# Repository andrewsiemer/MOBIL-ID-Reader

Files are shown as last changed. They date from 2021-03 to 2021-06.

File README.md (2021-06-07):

# MOBIL-ID Reader



## What is MOBIL-ID?
#### A Python web service & embedded reader for Apple PassKit

The MOBIL-ID project is an engineering systems capstone project for Oklahoma Christian University. The team’s mission statement is to create a mobile platform front-end to Oklahoma Christian University’s user management system. Students and Faculty will use their mobile ID to gain chapel attendance, enter the university cafeteria, and pay using Eagle Bucks.

### MOBIL-ID Reader
The MOBIL-ID Reader is a slave device responsible for scanning MOBIL-ID passes. It captures the QR data from a scanned pass and sends it in a GET request to the MOBIL-ID Server. The MOBIL-ID Server returns the associated user ID number. The MOBIL-ID Reader then hands the ID number to the transactional system via the USB connection. Below is a guide to creating a fully functional MOBIL-ID Reader.

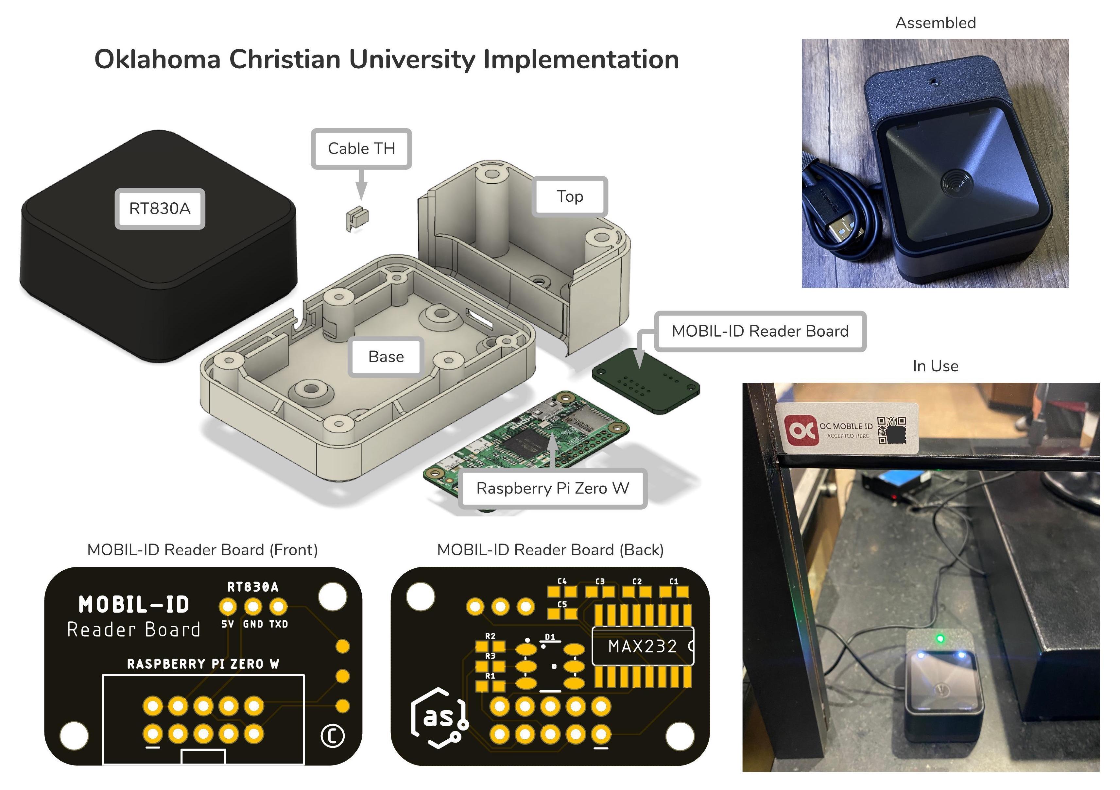
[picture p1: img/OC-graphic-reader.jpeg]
OC-graphic


### MOBIL-ID Server
The MOBIL-ID Server is a Python web service responsible for creating, deploying, and updating passes using Apple PassKit & Google Pay API. It tracks the pass’s complete lifecycle. When a user requests a pass, the server gets the user's data from OC’s database, creates a new pass, and signs it before delivering it to the user. It keeps a log of every pass it creates. When a user adds the pass to Apple Wallet, the pass will send a registration request to our server. The server will log the device id and pass relationship. When users data is changed, the MOBIL-ID server then knows what device to send the update push notification to. If a user deletes a pass of their device, the server will receive a request to delete the pass and it will be deleted from the server’s database and no longer receive updates. The user will also recieve real-time push notifications when pass data has change. [View MOBIL-ID Server](https://github.com/andrewsiemer/MOBIL-ID-Server)

### The MOBIL-ID Team
* Andrew Siemer - Electrical/Software Engineer - Team Lead
* Jacob Button - Electrical/Software Engineer
* Kyla Tarpey - Electrical Engineer
* Zach Jones - Computer/Software Engineer

### Acknowledgments
- Steve Maher - Mentor
- Luke Hartman - Customer
- Peyton Chenault - System Integrator

This work is licensed under a
[Creative Commons Attribution-NonCommercial-ShareAlike 4.0 International License](http://creativecommons.org/licenses/by-nc-sa/4.0/).

---

## Hardware Setup
The Hardware Setup Guide is a long but detailed document that steps through the entire process of creating a MOBIL-ID Reader. The document can be viewed or downloaded from the link below.

### [View Hardware Setup Guide](https://docs.google.com/document/d/1EBEo_Zr7OZ9AODJT-2cf_hYnRvtXFjDW9OjWyJNuSes)

## Software Setup
### Prerequisites
* [Install Raspberry Pi OS LITE using Raspberry Pi Imager](https://www.raspberrypi.org/software/)
* [Headless Raspberry Pi Setup](https://pimylifeup.com/headless-raspberry-pi-setup/)

### Raspberry Pi First Boot
Before we start, check that you have:

* A clean installation of Raspberry Pi OS LITE on a microSD card
* Added the `ssh` file to the `/boot` directory
* Added the `wpa_supplicant.conf` file to the `/boot` directory

**You will not be able to continue without completing these steps. Use the links above to properly allow headless setup.**

If you are confident you have completed the steps above, put the microSD card into the Raspberry Pi and plug the USB power cable in.
You should hear a startup beep and the LED on the MOBIL-ID Reader Board should be magenta. If one of theses did not happen, you will need to troubleshoot your hardware setup.

### Login to Raspberry Pi Remotely
In macOS/Linux, open Terminal and enter:
```sh
ssh pi@raspberrypi.local
```
The default password is `raspberry`.

### Run the MOBIL-ID Reader Installer
Once you are logged into as user `pi` run:
``` sh
curl https://raw.githubusercontent.com/andrewsiemer/MOBIL-ID-Reader/main/install.sh > install.sh && sudo bash install.sh
```
This script installs software for the MOBIL-ID Reader on the Raspberry Pi.

This includes:

* Creating a new hostname & password
* Updating the package index files (apt-get update)
* Installing prerequisite software
* Installing MOBIL-ID software and examples
* Configuring boot options

**Run time ~20 minutes. Reboot recommended after install. EXISTING INSTALLATION, IF ANY, WILL BE OVERWRITTEN.**

> The MOBIL-ID Reader will not work correctly until the system has been rebooted.

---

## MOBIL-ID Reader Status Codes
Once the MOBIL-ID Reader software is installed correctly and has been rebooted, the unit will use the LED on the MOBIL-ID Reader Board to show its status.

| LED Color | Description |
| --- | --- |
| Magenta | reader powered, starting program (~1 min) |
| Turquoise | connecting to network/updating software (<30 secs) |
| Yellow | waiting to connect to server |
| Green | connected, ready to scan |
| Red | processing scan |

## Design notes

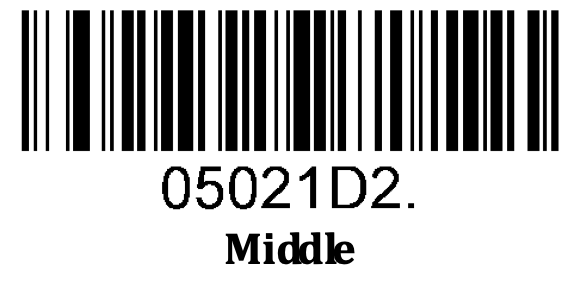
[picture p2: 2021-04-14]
img/beep-medium.png

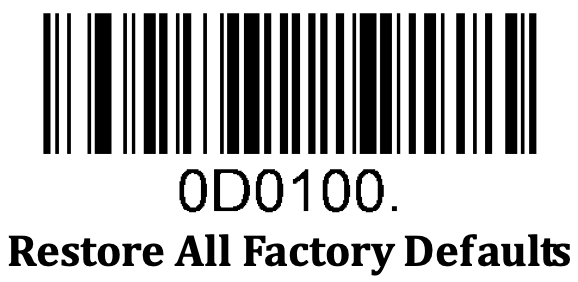
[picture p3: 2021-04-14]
img/restore-defaults.png

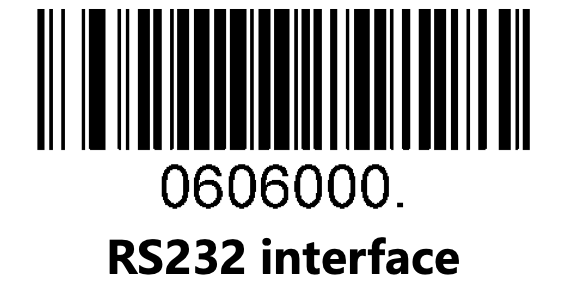
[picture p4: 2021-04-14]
img/RS232.png

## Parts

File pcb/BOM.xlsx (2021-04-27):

Comment | Designator | Footprint | LCSC Part #
330 | R1 | 603 | C23138
330 | R2 | 603 | C23138
330 | R3 | 603 | C23138
1u | C1 | 603 | C15849
1u | C2 | 603 | C15849
1u | C3 | 603 | C15849
1u | C4 | 603 | C15849
1u | C5 | 603 | C15849
5050 RGB | D1 | 5050 | C193878 | C784540
Maxim MAX232 | MAX232 | MAX232ECWES | C26860

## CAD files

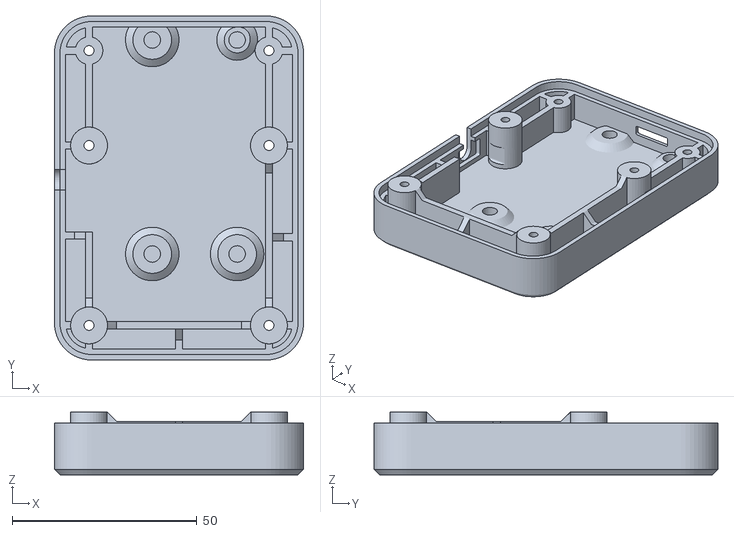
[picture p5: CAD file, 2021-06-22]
stl/Base.stl
67.5 x 93.2 x 17.0

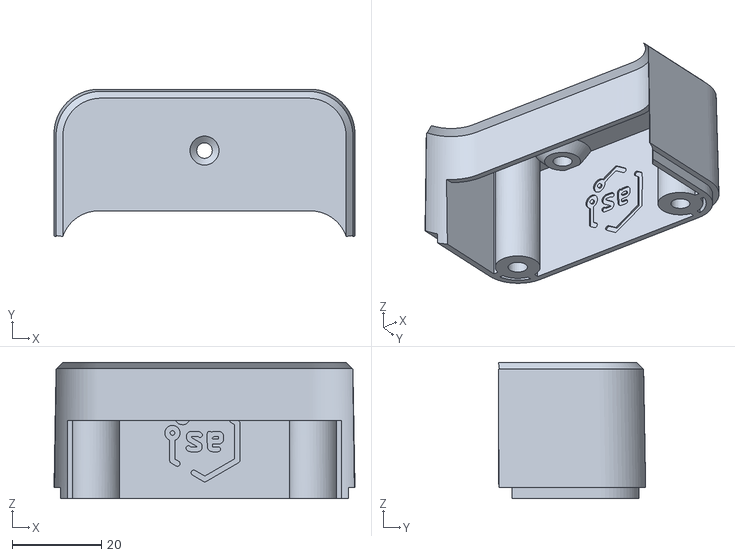
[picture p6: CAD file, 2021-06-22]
stl/Top.stl
67.5 x 33.1 x 30.5

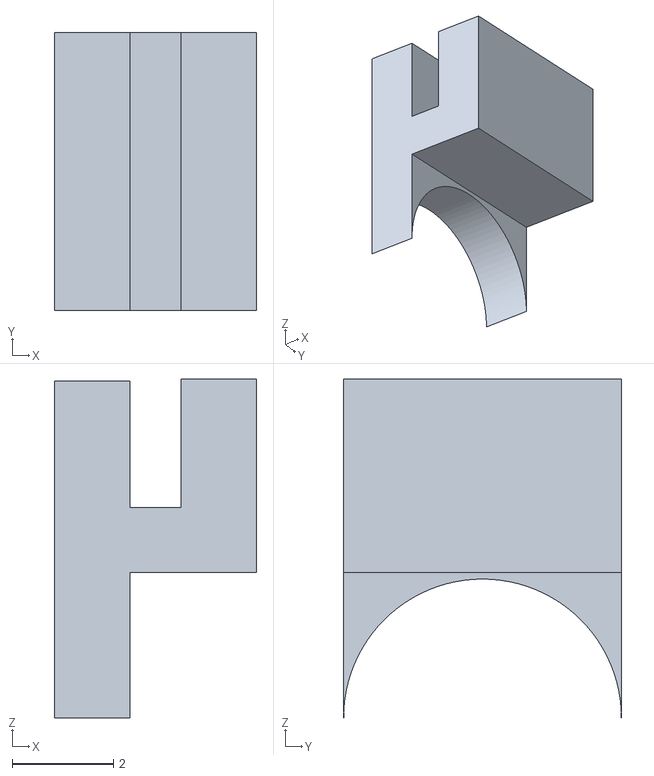
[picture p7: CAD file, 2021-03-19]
stl/Cable TH.stl
4.00 x 5.50 x 6.71

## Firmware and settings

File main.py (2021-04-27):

''' main.py: A Python QR code reader and USB-HID keyboard emulator
Built to interact with the MOBIL-ID web service for Apple PassKit '''

import time, subprocess

import serial, requests, git

import config
from include.hid import Keyboard
from include.rgb import C193878

# Create keyboard object for HID keyboard emulation
ser = None
kbd = Keyboard()
led = C193878(2,4,3)
WEB_SERVICE_URL = 'https://mobileid.oc.edu'

def check_for_updates():
    '''
    Checks for updates from GitHub, 
    if update availiable, installs and restarts service
    '''
    print('Checking for update...')
    led.set_turquoise()

    try:
        repo = git.Repo('/home/pi/MOBIL-ID-Reader')

        current = repo.head.commit
        repo.remotes.origin.pull()
        if current != repo.head.commit:
            print("Installing updates...")
            repo.remotes.origin.pull()
            subprocess.call('sudo systemctl restart mobil-id.service', shell=True)
            quit()
    except:
        pass

# Setup UART for TTL signal from MAX232 chip
def setup_serial():
    '''
    Sets up serial object for RTscan830A
    '''
    print('Setting up serial port...')
    global ser
    ser = serial.Serial(
        port='/dev/ttyS0',
        baudrate = 115200,
        parity=serial.PARITY_NONE,
        stopbits=serial.STOPBITS_ONE,
        bytesize=serial.EIGHTBITS,
        timeout=0.01
    )

def setup_ibeacon():
    '''
    Turns on bluetooth iBeacon
    '''
    print('Turning on iBeacon...')
    led.set_blue()
    
    subprocess.call('sudo hciconfig hci0 up', shell=True)
    subprocess.call('sudo hciconfig hci0 leadv 3', shell=True)
    subprocess.call('sudo hcitool -i hci0 cmd 0x08 0x0008 1E 02 01 06 1A FF 4C 00 02 15 1F 23 44 54 CF 6D 4A 0F AD F2 F4 91 1B A9 FF A9 00 01 00 01 C8 00', shell=True)

def ping_server():
    '''
    Pings server until valid response
    '''
    while 1:
        led.off()
        try:
            r = requests.get(WEB_SERVICE_URL, timeout=1, verify=False)
            if r.status_code == 200:
                break
            else:
                raise Exception('')
        except:
            led.set_yellow()
            time.sleep(1)


if __name__ == "__main__":

    check_for_updates()
    ping_server()
    setup_serial()
    setup_ibeacon()

    while 1:
        led.set_green()
        # read line from UART
        x = ser.readline()
        # input recived, start timer
        #start = time.time()
        if len(x) > 1:
            led.set_red()
            try:
                # if input is more than a CR,
                # decode binary data to str
                qr_hash = x.decode('utf-8')

                # try to GET ID number from server
                r = requests.get(WEB_SERVICE_URL + '/scan/' + qr_hash + '?reader=' + config.SERIAL_NUMBER, timeout=1, verify=False)
                if r.status_code == 200:
                    id_number = r.json()

                    # write ID number to host keyboard
                    kbd.write(str(id_number) + '\n')

                    #print('QR Hash: ' + qr_hash + '     ID Number: ' + id_number + '     (' + str(round(((time.time() - start)*1000), 2)) + ' ms)')
                else:
                    raise Exception('204')

            except Exception as error:
                # exception during GET request,
                # return HTTP status code
                print(error)
                if error != '204':
                    ping_server()

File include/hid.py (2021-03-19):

'''
hid.py: A library to emulate a keyboard using USB-HID
'''

import time

class Keycode:
    #pylint: disable-msg=invalid-name
    A = 0x04
    """``a`` and ``A``"""
    B = 0x05
    """``b`` and ``B``"""
    C = 0x06
    """``c`` and ``C``"""
    D = 0x07
    """``d`` and ``D``"""
    E = 0x08
    """``e`` and ``E``"""
    F = 0x09
    """``f`` and ``F``"""
    G = 0x0A
    """``g`` and ``G``"""
    H = 0x0B
    """``h`` and ``H``"""
    I = 0x0C
    """``i`` and ``I``"""
    J = 0x0D
    """``j`` and ``J``"""
    K = 0x0E
    """``k`` and ``K``"""
    L = 0x0F
    """``l`` and ``L``"""
    M = 0x10
    """``m`` and ``M``"""
    N = 0x11
    """``n`` and ``N``"""
    O = 0x12
    """``o`` and ``O``"""
    P = 0x13
    """``p`` and ``P``"""
    Q = 0x14
    """``q`` and ``Q``"""
    R = 0x15
    """``r`` and ``R``"""
    S = 0x16
    """``s`` and ``S``"""
    T = 0x17
    """``t`` and ``T``"""
    U = 0x18
    """``u`` and ``U``"""
    V = 0x19
    """``v`` and ``V``"""
    W = 0x1A
    """``w`` and ``W``"""
    X = 0x1B
    """``x`` and ``X``"""
    Y = 0x1C
    """``y`` and ``Y``"""
    Z = 0x1D
    """``z`` and ``Z``"""

    ONE = 0x1E
    """``1`` and ``!``"""
    TWO = 0x1F
    """``2`` and ``@``"""
    THREE = 0x20
    """``3`` and ``#``"""
    FOUR = 0x21
    """``4`` and ``$``"""
    FIVE = 0x22
    """``5`` and ``%``"""
    SIX = 0x23
    """``6`` and ``^``"""
    SEVEN = 0x24
    """``7`` and ``&``"""
    EIGHT = 0x25
    """``8`` and ``*``"""
    NINE = 0x26
    """``9`` and ``(``"""
    ZERO = 0x27
    """``0`` and ``)``"""
    ENTER = 0x28
    """Enter (Return)"""
    RETURN = ENTER
    """Alias for ``ENTER``"""
    ESCAPE = 0x29
    """Escape"""
    BACKSPACE = 0x2A
    """Delete backward (Backspace)"""
    TAB = 0x2B
    """Tab and Backtab"""
    SPACEBAR = 0x2C
    """Spacebar"""
    SPACE = SPACEBAR
    """Alias for SPACEBAR"""
    MINUS = 0x2D
    """``-` and ``_``"""
    EQUALS = 0x2E
    """``=` and ``+``"""
    LEFT_BRACKET = 0x2F
    """``[`` and ``{``"""
    RIGHT_BRACKET = 0x30
    """``]`` and ``}``"""
    BACKSLASH = 0x31
    r"""``\`` and ``|``"""
    POUND = 0x32
    """``#`` and ``~`` (Non-US keyboard)"""
    SEMICOLON = 0x33
    """``;`` and ``:``"""
    QUOTE = 0x34
    """``'`` and ``"``"""
    GRAVE_ACCENT = 0x35
    r""":literal:`\`` and ``~``"""
    COMMA = 0x36
    """``,`` and ``<``"""
    PERIOD = 0x37
    """``.`` and ``>``"""
    FORWARD_SLASH = 0x38
    """``/`` and ``?``"""

    CAPS_LOCK = 0x39
    """Caps Lock"""

    F1 = 0x3A
    """Function key F1"""
    F2 = 0x3B
    """Function key F2"""
    F3 = 0x3C
    """Function key F3"""
    F4 = 0x3D
    """Function key F4"""
    F5 = 0x3E
    """Function key F5"""
    F6 = 0x3F
    """Function key F6"""
    F7 = 0x40
    """Function key F7"""
    F8 = 0x41
    """Function key F8"""
    F9 = 0x42
    """Function key F9"""
    F10 = 0x43
    """Function key F10"""
    F11 = 0x44
    """Function key F11"""
    F12 = 0x45
    """Function key F12"""

    PRINT_SCREEN = 0x46
    """Print Screen (SysRq)"""
    SCROLL_LOCK = 0x47
    """Scroll Lock"""
    PAUSE = 0x48
    """Pause (Break)"""

    INSERT = 0x49
    """Insert"""
    HOME = 0x4A
    """Home (often moves to beginning of line)"""
    PAGE_UP = 0x4B
    """Go back one page"""
    DELETE = 0x4C
    """Delete forward"""
    END = 0x4D
    """End (often moves to end of line)"""
    PAGE_DOWN = 0x4E
    """Go forward one page"""

    RIGHT_ARROW = 0x4F
    """Move the cursor right"""
    LEFT_ARROW = 0x50
    """Move the cursor left"""
    DOWN_ARROW = 0x51
    """Move the cursor down"""
    UP_ARROW = 0x52
    """Move the cursor up"""

    KEYPAD_NUMLOCK = 0x53
    """Num Lock (Clear on Mac)"""
    KEYPAD_FORWARD_SLASH = 0x54
    """Keypad ``/``"""
    KEYPAD_ASTERISK = 0x55
    """Keypad ``*``"""
    KEYPAD_MINUS = 0x56
    """Keyapd ``-``"""
    KEYPAD_PLUS = 0x57
    """Keypad ``+``"""
    KEYPAD_ENTER = 0x58
    """Keypad Enter"""
    KEYPAD_ONE = 0x59
    """Keypad ``1`` and End"""
    KEYPAD_TWO = 0x5A
    """Keypad ``2`` and Down Arrow"""
    KEYPAD_THREE = 0x5B
    """Keypad ``3`` and PgDn"""
    KEYPAD_FOUR = 0x5C
    """Keypad ``4`` and Left Arrow"""
    KEYPAD_FIVE = 0x5D
    """Keypad ``5``"""
    KEYPAD_SIX = 0x5E
    """Keypad ``6`` and Right Arrow"""
    KEYPAD_SEVEN = 0x5F
    """Keypad ``7`` and Home"""
    KEYPAD_EIGHT = 0x60
    """Keypad ``8`` and Up Arrow"""
    KEYPAD_NINE = 0x61
    """Keypad ``9`` and PgUp"""
    KEYPAD_ZERO = 0x62
    """Keypad ``0`` and Ins"""
    KEYPAD_PERIOD = 0x63
    """Keypad ``.`` and Del"""
    KEYPAD_BACKSLASH = 0x64
    """Keypad ``\\`` and ``|`` (Non-US)"""

    APPLICATION = 0x65
    """Application: also known as the Menu key (Windows)"""
    POWER = 0x66
    """Power (Mac)"""
    KEYPAD_EQUALS = 0x67
    """Keypad ``=`` (Mac)"""
    F13 = 0x68
    """Function key F13 (Mac)"""
    F14 = 0x69
    """Function key F14 (Mac)"""
    F15 = 0x6A
    """Function key F15 (Mac)"""
    F16 = 0x6B
    """Function key F16 (Mac)"""
    F17 = 0x6C
    """Function key F17 (Mac)"""
    F18 = 0x6D
    """Function key F18 (Mac)"""
    F19 = 0x6E
    """Function key F19 (Mac)"""

    LEFT_CONTROL = 0xE0
    """Control modifier left of the spacebar"""
    CONTROL = LEFT_CONTROL
    """Alias for LEFT_CONTROL"""
    LEFT_SHIFT = 0xE1
    """Shift modifier left of the spacebar"""
    SHIFT = LEFT_SHIFT
    """Alias for LEFT_SHIFT"""
    LEFT_ALT = 0xE2
    """Alt modifier left of the spacebar"""
    ALT = LEFT_ALT
    """Alias for LEFT_ALT; Alt is also known as Option (Mac)"""
    OPTION = ALT
    """Labeled as Option on some Mac keyboards"""
    LEFT_GUI = 0xE3
    """GUI modifier left of the spacebar"""
    GUI = LEFT_GUI
    """Alias for LEFT_GUI; GUI is also known as the Windows key, Command (Mac), or Meta"""
    WINDOWS = GUI
    """Labeled with a Windows logo on Windows keyboards"""
    COMMAND = GUI
    """Labeled as Command on Mac keyboards, with a clover glyph"""
    RIGHT_CONTROL = 0xE4
    """Control modifier right of the spacebar"""
    RIGHT_SHIFT = 0xE5
    """Shift modifier right of the spacebar"""
    RIGHT_ALT = 0xE6
    """Alt modifier right of the spacebar"""
    RIGHT_GUI = 0xE7
    """GUI modifier right of the spacebar"""

    @classmethod
    def modifier_bit(cls, keycode):
        """Return the modifer bit to be set in an HID keycode report if this is a
        modifier key; otherwise return 0."""
        return 1 << (keycode - 0xE0) if cls.LEFT_CONTROL <= keycode <= cls.RIGHT_GUI else 0
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

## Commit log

2021-04-01 Fix UART config
2021-04-09 Increase screw hole size
    [Base.stl]
2021-04-27 Modified holes for different screw heads
    [Base.stl]
2021-04-27 Modified LED cutout for PCB rev C
    [Top.stl]
2021-04-27 Added PCB rev C
2021-04-27 Added SMT files for JLCPCB assembly
    [BOM.xlsx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]
2021-06-22 Allow larger screw heads
    [Base.stl, Top.stl]

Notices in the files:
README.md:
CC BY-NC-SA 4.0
